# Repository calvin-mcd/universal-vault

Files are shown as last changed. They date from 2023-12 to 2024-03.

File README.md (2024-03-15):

# HHKB universal-vault

The HHKB universal vault aka "omnivault" aka "v-all-t" is a community, open source pcb for the HHKB vault35. It tries to cover as many alpha layouts as possible while maintaining the original bottom row of the vault35. It uses a STM32F072 to reduce the amount of components while still supporting RGB for underglow.

## Layout

The following Alpha Layouts are included and labelled with letters:

- V = Original Vault Layout
- A = Alpha Stagger
- O = Ortho
- K = Katana
- U = Uniform Stagger
- T = Treadstone

1 Oled is supported in two positions. 2 Rotaries are supported in separate positions. There are various options for ISO and other keys.

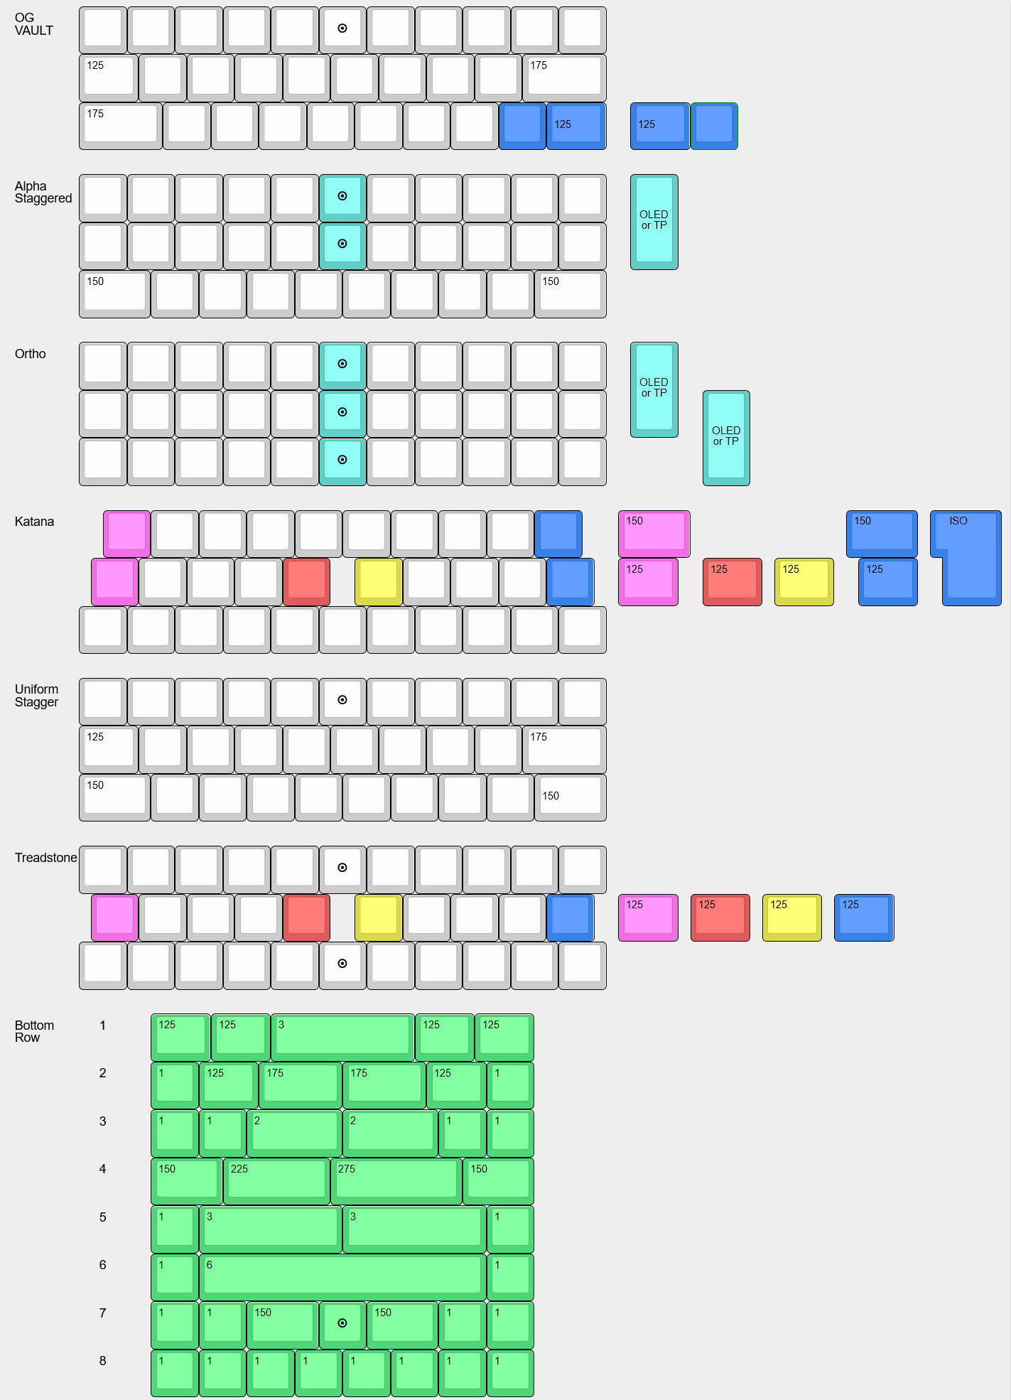
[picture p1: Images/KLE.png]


[Link](http://www.keyboard-layout-editor.com/#/gists/3ef7aba83f82a949b1ddb73d159c1351)

## Images

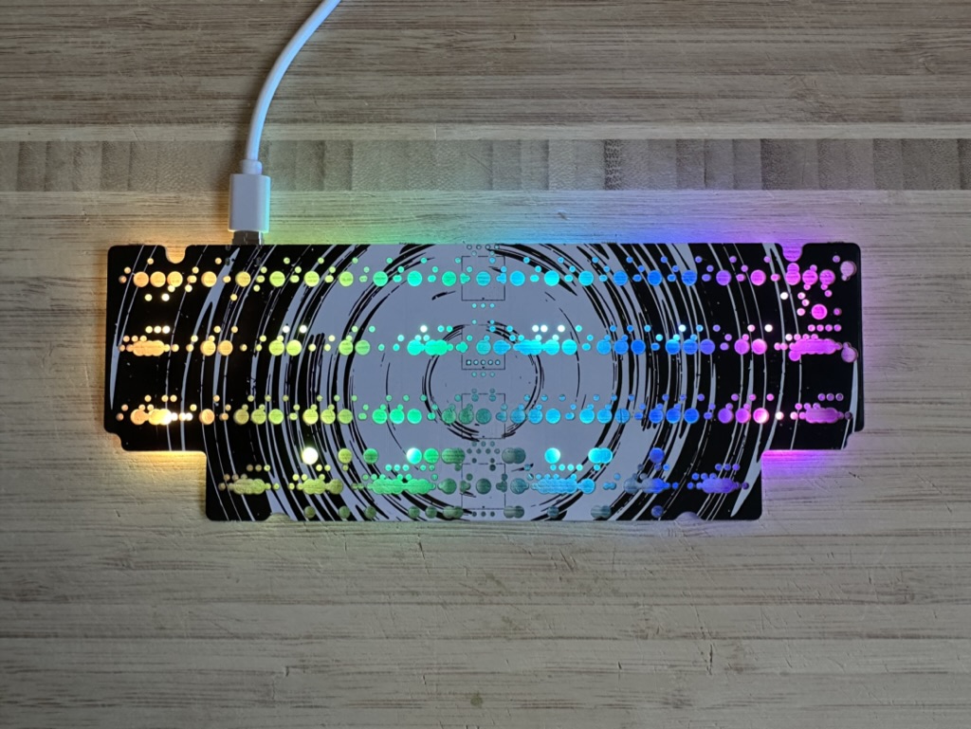
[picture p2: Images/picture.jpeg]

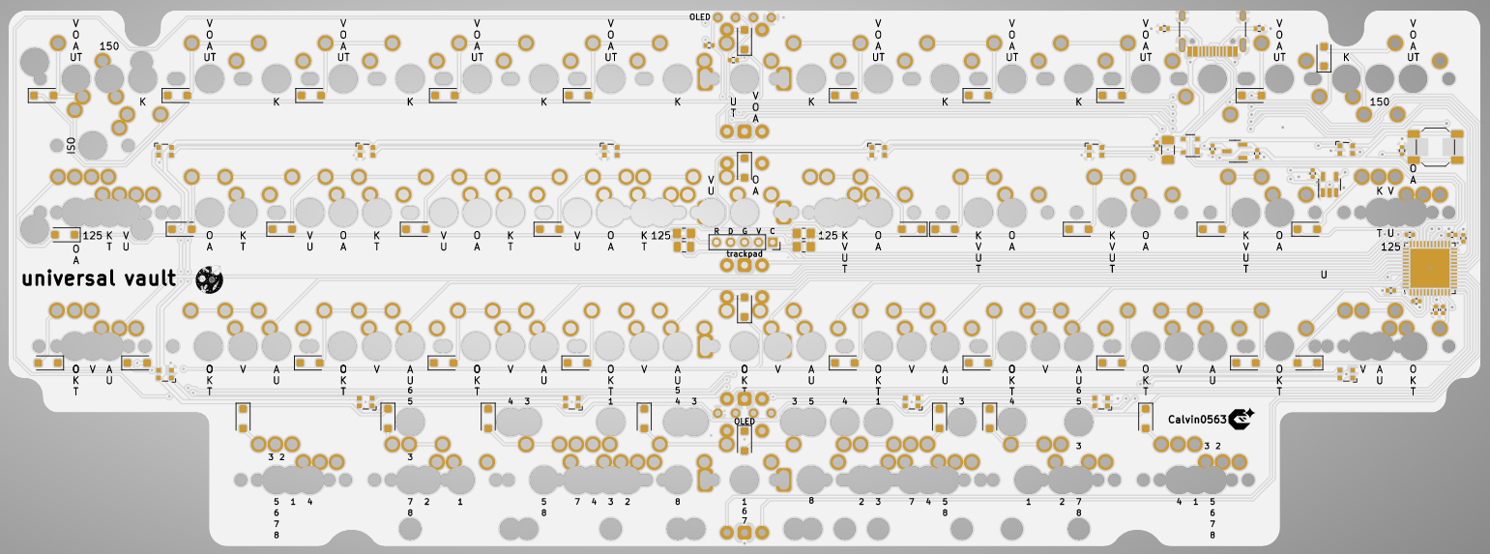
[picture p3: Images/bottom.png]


## Firmware

The firmware file for flashing can be found in the folder. As this pcb uses a STM mcu, you will need to hold the boot button before plugging in the pcb. Then use qmk toolbox to flash (you don't need to select an MCU, just the firmware file').

## Disclaimer

This PCB has been fully tested and is confirmed to work. However, no-one involved in this project is responsible for any usage issues that may arise. Order at your own risk. Feel free to edit, modify and otherwise utilise these files.

## License

This project is released under the GPL v3 License. Please refer to the LICENCE file.

## Credits

big thanks to cain (mechvault) for the amazing vault35, a design that just keeps giving.

thanks also to jlw_ for the inspiration and support with this silly project. To galvy for their work on other community pcbs and the work that I could draw from. To chronomap for help with the KLE. And to max.yw, Ha Ha Ha
and ottimo for name suggestions!!!! :big heart:

and finally big thanks to summerqm for their work on the silkscreen!!!

As always big thanks to the whole 40s keyboard community!

Any questions, contact Calvin0563 on Discord.

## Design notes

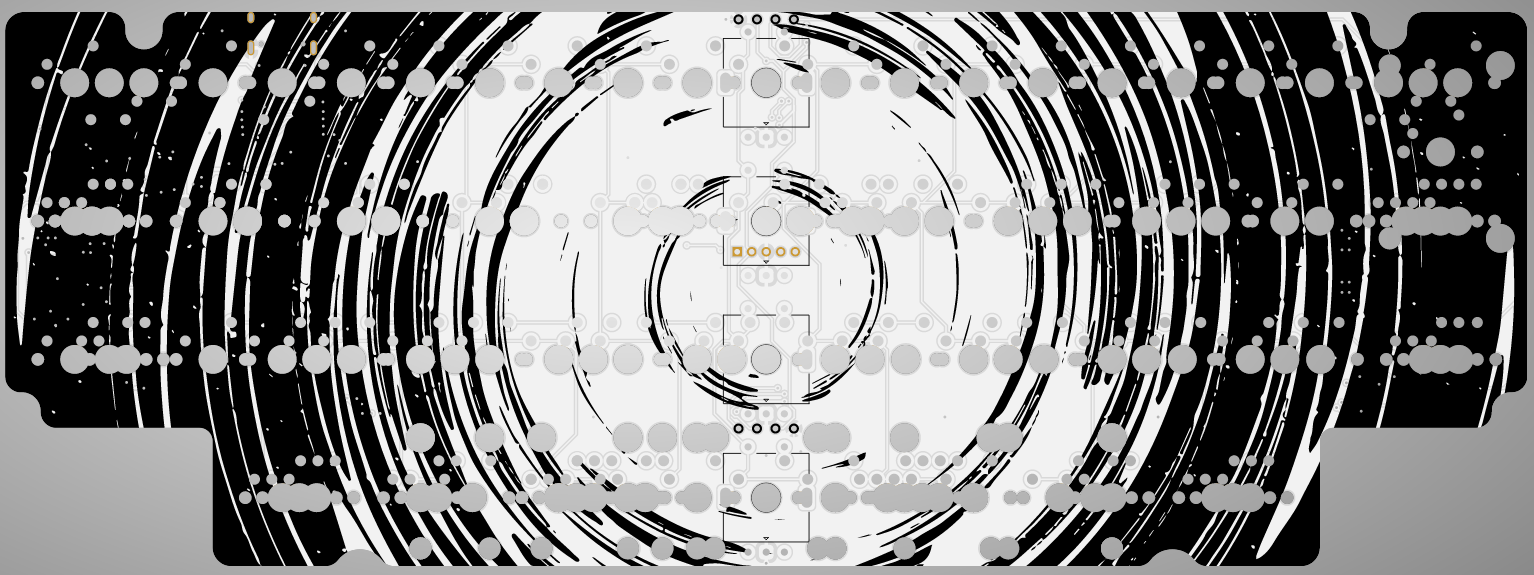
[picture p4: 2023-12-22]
Images/top.png

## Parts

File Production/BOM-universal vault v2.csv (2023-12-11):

Comment | Designator | Footprint | LCSC
SKQGABE010 | SW4 | SW_SPST_SKQG_WithStem | C115351
74AHCT1G125 | U3 | TSOT-23-5 | C12494
ASMD1206-150 | F2 | Fuse_1206_3216Metric | C135341
1uF | C10,C8 | C_0402_1005Metric | C14445
100nF | C1,C11,C2,C3,C4,C5,C7,C9 | C_0402_1005Metric | C1525
USB_C_Receptacle_USB2.0 | J1 | USB_C_Receptacle_HRO_TYPE-C-31-M-12 | C165948
4.7k | UR1,UR2 | R_0805_2012Metric_Pad1.20x1.40mm_HandSolder | C17673
2.2uF | C12 | C_0805_2012Metric | C19110
100k | UR3 | R_0805_2012Metric_Pad1.20x1.40mm_HandSolder | C25611
10k | R1 | R_0402_1005Metric | C25744
4.7k | R4,R5 | R_0402_1005Metric | C25900
5.1k | R2,R3 | R_0402_1005Metric | C25905
PRTR5V0U2X | D1 | SOT-143 | C2827688
10uF | C6 | C_0402_1005Metric | C315248
XC6206PxxxMR | U2 | SOT-23-3 | C5446
D | D_SPACE1,D_SPACE10,D_SPACE11,D_SPACE12,D_SPACE13,D_SPACE14,D_SPACE15,D_SPACE16,D_SPACE17,D_SPACE18,D_SPACE19,D_SPACE2,D_SPACE20,D_SPACE21,D_SPACE22,D_SPACE23,D_SPACE24,D_SPACE25,D_SPACE26,D_SPACE27,D_SPACE28,D_SPACE29,D_SPACE3,D_SPACE30,D_SPACE31,D_SPACE32,D_SPACE33,D_SPACE34,D_SPACE35,D_SPACE36,D_SPACE37,D_SPACE38,D_SPACE39,D_SPACE4,D_SPACE40,D_SPACE42,D_SPACE5,D_SPACE6,D_SPACE7,D_SPACE8,D_SPACE9 | D_SOD-123F | C81598
STM32F072CBUx | U1 | QFN-48-1EP_7x7mm_P0.5mm_EP5.6x5.6mm | C92504
WS2812_2020 | LED1,LED10,LED11,LED12,LED2,LED3,LED4,LED5,LED6,LED7,LED8,LED9 | LED_WS2812_2020 | C965555

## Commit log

2023-11-20 inititalise project
    [BOM-universal vault.csv, plate.kicad_pcb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]
2023-11-21 added I2C pull up
    added I2C pull up and updated production files
    [BOM-universal vault.csv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]
2023-11-21 Updated BOM with part numbers
    jlw is bad at checking his workbefore committing changes
    [BOM-universal vault.csv]
2023-11-22 small routing changes, fresh production files
    [BOM-universal vault.csv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]
2023-11-22 moved files
    [BOM-universal vault.csv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]
2023-12-11 small revision
    added trackpad support, more bottom row support & 1 rotary
    [BOM-universal vault.csv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]
2023-12-16 added v2 to make the HHKB universal closer to the WKL, revised routing
    [universal vault v2-B_Cu.gbl, universal vault v2-B_Mask.gbs, universal vault v2-B_Silkscreen.gbo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]
2023-12-19 version 2 finished, production files created
    [BOM-universal vault v2.csv, BOM-universal vault.csv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]
2023-12-19 deleted previous version
    [universal vault.kicad_sch]
2023-12-19 Update universal vault v2.kicad_pcb
2024-01-31 changed rgb pin for better software hardware compatibility & fresh production files
    [BOM-universal vault v2.csv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]
2024-03-15 Revert "changed rgb pin for better software hardware compatibility & fresh production files"
    This reverts commit 76bec49334091c1669f5db898bd2653646399791.
    [BOM-universal vault v2.csv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]
2024-03-15 production files
    [bom.csv, positions.csv]
2024-03-15 project updated & cleaned up
    [bom.csv, hhkb universal.kicad_sch, plate.kicad_pcb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]
2025-08-14 Update hhkb universal.kicad_prl
